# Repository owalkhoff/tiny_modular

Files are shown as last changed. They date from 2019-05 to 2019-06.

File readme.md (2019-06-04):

# tinyModular

## What is this project about?

This is a modular synthesizer built around the ATtiny microcontroller. All modules have identical hardware, and can be programmed to become oscillators, filters, noise generators, etc.

This project is based on the original miniMO by Jose Gonzalez: [minimosynth.com](https://minimosynth.com). Software and instructions can be found there too.

## Design goals for the first version

Edition One is my first attempt to create a [Eurorack](https://en.wikipedia.org/wiki/Eurorack) module based on the original miniMO. The goal was to create a module that can be quickly and easily built using DIY methods, on a single PCB, with as few as possible through hole components, no vias and without wiring. The schematic was redrawn from the original by Jose Gonzalez.

## Images

Here is an image of the first built module:

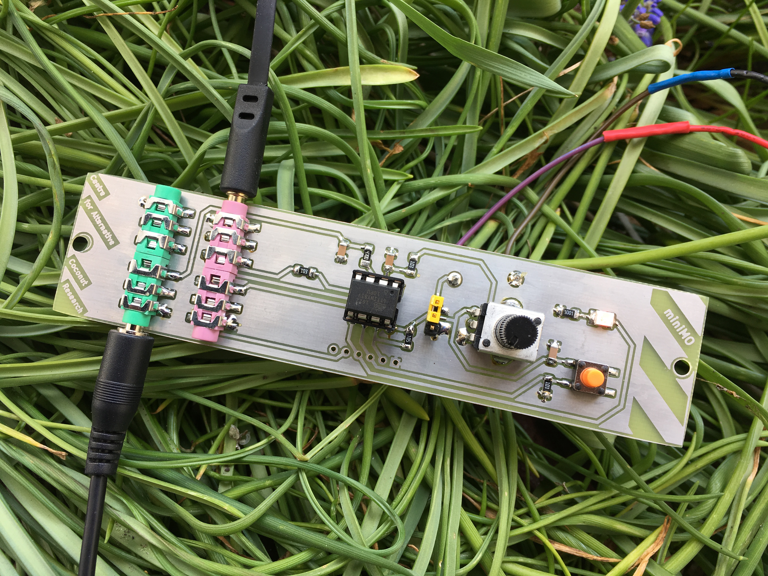
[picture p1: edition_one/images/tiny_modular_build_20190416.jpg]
first build


Here is a rendering of the PCB, with some components:

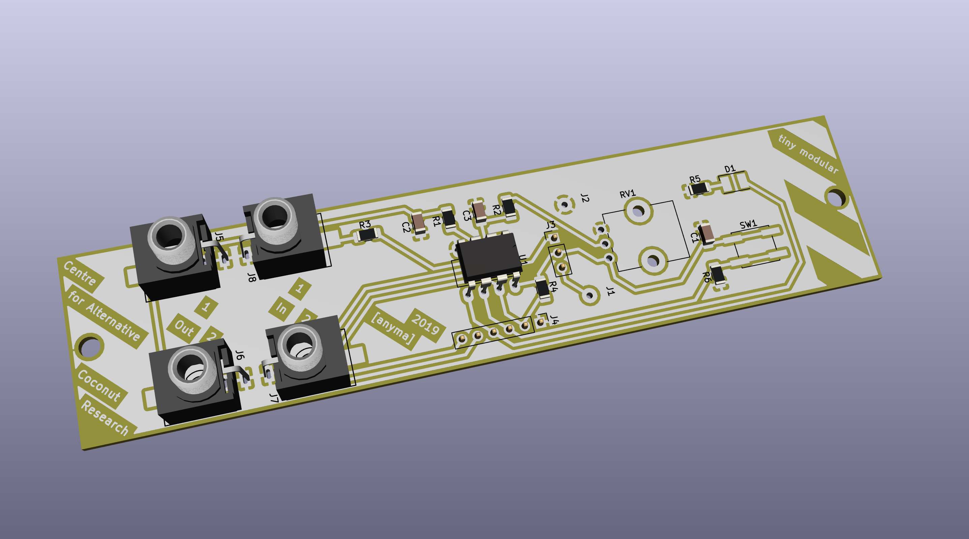
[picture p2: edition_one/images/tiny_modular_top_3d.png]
rendering pcb top


## PDFs

The PCB layout used for printing on transparency film:

[tiny_modular_pcb.pdf](edition_one/pdf/tiny_modular_pcb.pdf)

The schematic:

[tiny_modular_schematic.pdf](edition_one/pdf/tiny_modular_schematic.pdf)

## KiCad files

The schematic and layout were drawn in KiCad 5.0.2. You can find the project [in this directory](edition_one/kicad_5).

## Caveats

~~The 3.5mm jacks should be positioned perpendicularly to the module front in order to be accessible, but there seems to be no jack on the market which can do this. A solution might be to add an auxiliary PCB for the jacks, soldered to the main PCB perpendicularly.~~

This has now been solved with Thonkiconn vertical 3.5mm jack sockets (PJ398SM) by thonk.co.uk, thanks to dusjagr. Bend pin 3 by 90 degrees so that it can be soldered to the pad smd style.

~~Pin 1 (J3) and pin 6 (J4) are still unconnected on this revision of the PCB. The idea is that pin 6 supplies power to the PCB when it is connected to a programmer with the jumper set for this on J3.~~

Fixed in this revision.

## License

The tinyModular circuit is CC NC BY minimosynth.com

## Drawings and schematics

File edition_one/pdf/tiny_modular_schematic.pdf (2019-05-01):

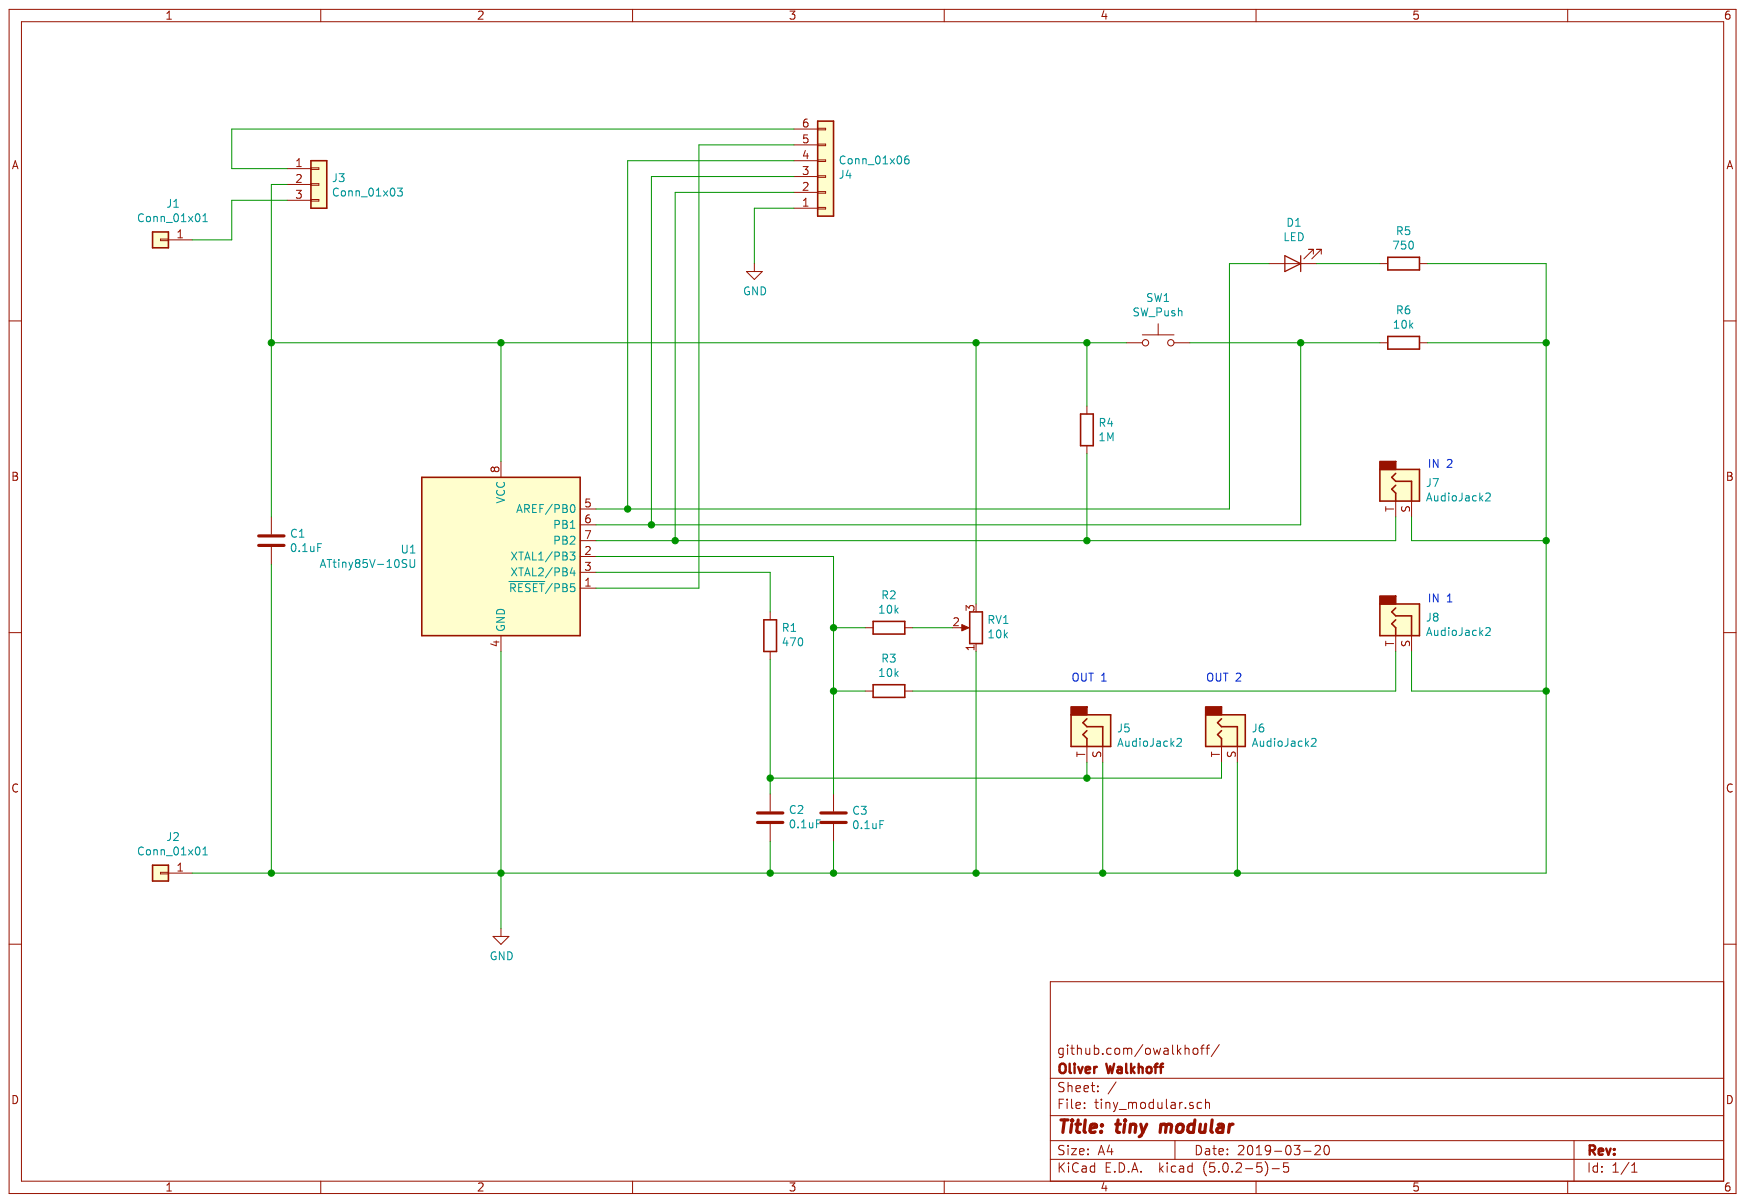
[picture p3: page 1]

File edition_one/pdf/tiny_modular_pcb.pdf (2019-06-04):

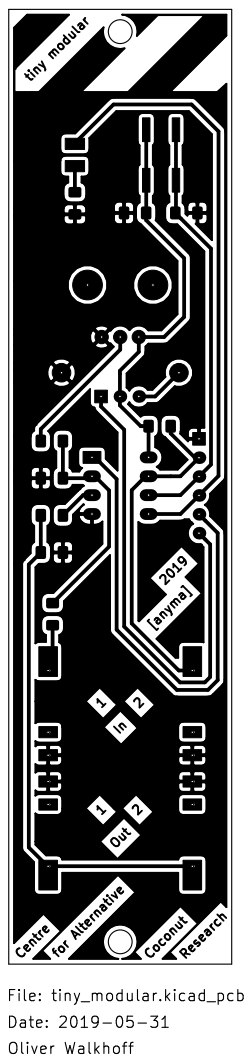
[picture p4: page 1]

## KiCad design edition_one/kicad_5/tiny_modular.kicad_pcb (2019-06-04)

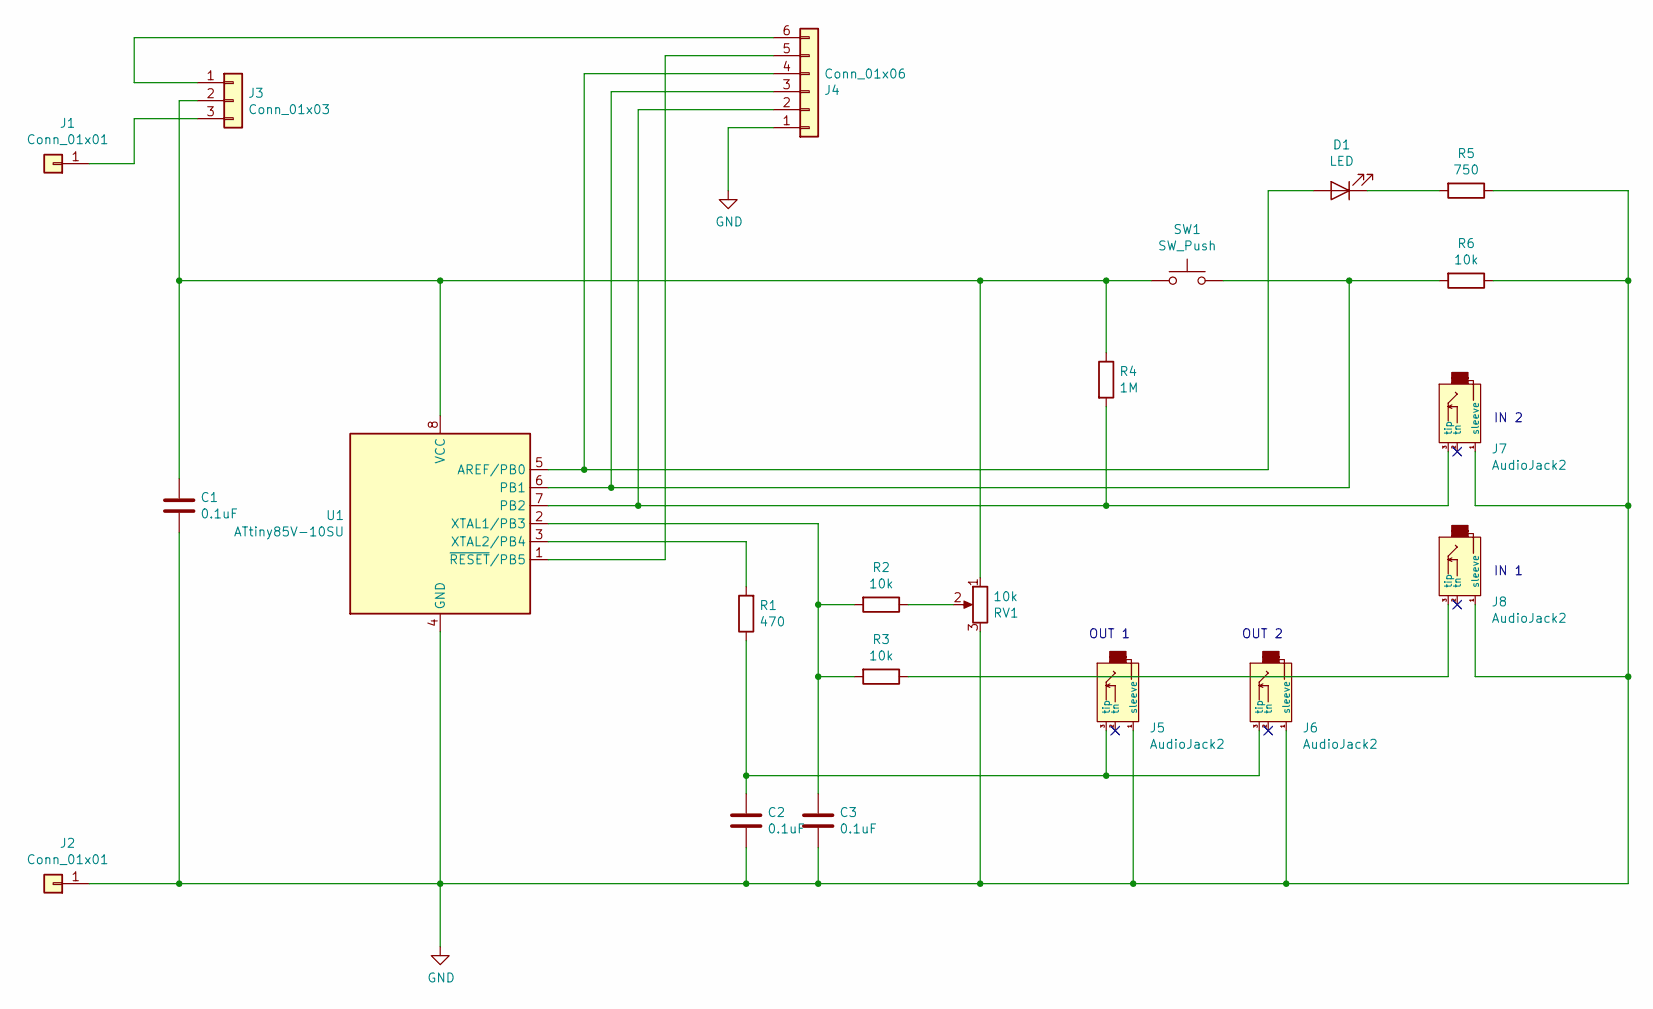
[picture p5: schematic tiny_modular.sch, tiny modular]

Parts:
C1, C2, C3: 0.1uF; C_1206_3216Metric_Pad1.42x1.75mm_HandSolder
D1: LED; LED_PLCC-2
J1, J2: Conn_01x01; SolderWirePad_1x01_Drill1mm
J3: Conn_01x03; PinHeader_1x03_P2.54mm_Vertical
J4: Conn_01x06; PinHeader_1x06_P2.54mm_Vertical
J5, J6, J7, J8: AudioJack2; PJ301M-12_bent
R1: 470; R_1206_3216Metric_Pad1.42x1.75mm_HandSolder
R2, R3, R6: 10k; R_1206_3216Metric_Pad1.42x1.75mm_HandSolder
R4: 1M; R_1206_3216Metric_Pad1.42x1.75mm_HandSolder
R5: 750; R_1206_3216Metric_Pad1.42x1.75mm_HandSolder
RV1: 10k; Potentiometer_Alps_RK09K_Single_Vertical
SW1: SW_Push; SW_SPST_EVQQ2
U1: ATtiny85V-10SU; DIP-8_W7.62mm_LongPads

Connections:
GND: C1.2, C2.1, C3.2, J2.1, J4.1, J5.1 (sleeve), J6.1 (sleeve), J7.1 (sleeve), J8.1 (sleeve), R5.1, R6.1, RV1.3, U1.4 (GND)
unnamed: C1.1, J3.2, R4.1, RV1.1, SW1.1, U1.8 (VCC)
unnamed: C2.2, J5.3 (tip), J6.3 (tip), R1.1
unnamed: C3.1, R2.2, R3.2, U1.2 (XTAL1/PB3)
unnamed: D1.1 (K), R5.2
unnamed: D1.2 (A), J4.4, U1.5 (AREF/PB0)
unnamed: J1.1, J3.3
unnamed: J3.1, J4.6
unnamed: J4.2, J7.3 (tip), R4.2, U1.7 (PB2)
unnamed: J4.3, R6.2, SW1.2, U1.6 (PB1)
unnamed: J4.5, U1.1 (~RESET~/PB5)
unnamed: J8.3 (tip), R3.1
unnamed: R1.2, U1.3 (XTAL2/PB4)
unnamed: R2.1, RV1.2

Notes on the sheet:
IN 1
IN 2
OUT 2
OUT 1

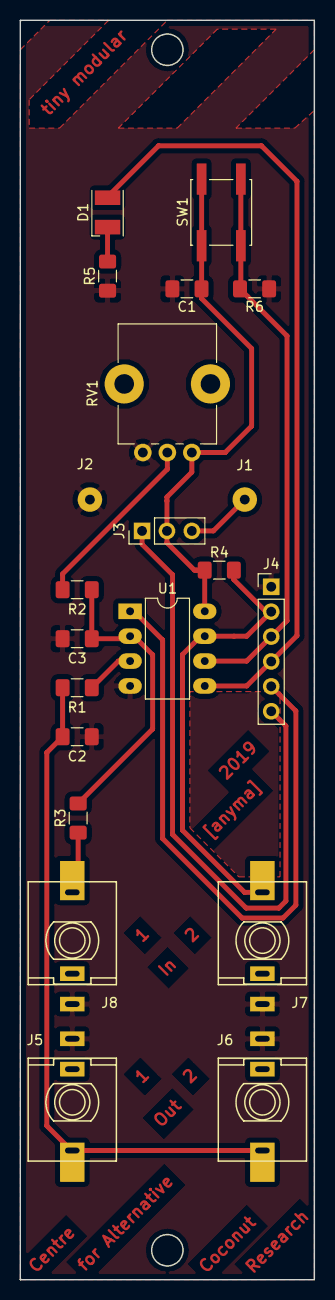
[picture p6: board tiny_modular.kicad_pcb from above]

Board: 2 copper layers, 30.0 x 128.5 mm, 21 parts (0 on the bottom side), 14 nets.
